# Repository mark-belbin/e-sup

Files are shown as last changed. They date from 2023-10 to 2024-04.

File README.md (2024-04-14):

# eSUP
HW and FW for motorized stand up paddle board (SUP). Includes BMS+Charger, MCU, and Battery-Holder PCBA designs.

## Motivation
1. Cruise around Foster City on a battery powered electric SUP.
2. Learn more about BMS HW and design.
3. Improve STM32 FW skills and knowledge.

## High-Level Block Diagram
Some aspects still TBD, but this is the general idea so far. BMS+Charger PCBA, Battery-Holder PCBAs, and MCU PCBA. May or may not need another custom PCBA for hand controller, might be possible to directly use or modify an OTS hand controller normally used for electric foil boards or skateboards.
System Block Diagram

## Battery Configuration

## Power Architecture

## Mechanical Design

## PCBA Design

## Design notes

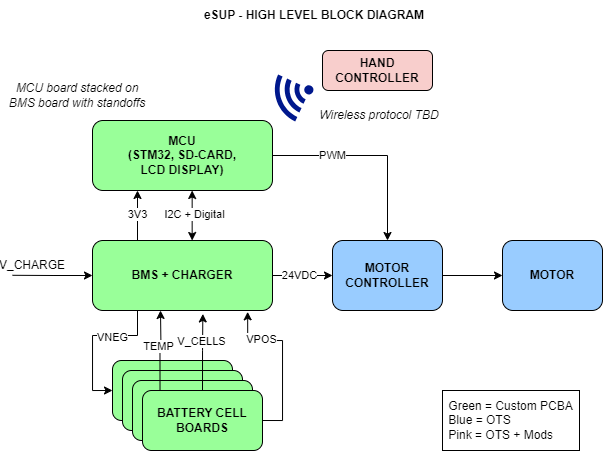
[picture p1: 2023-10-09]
docs/system_block_diagram.png

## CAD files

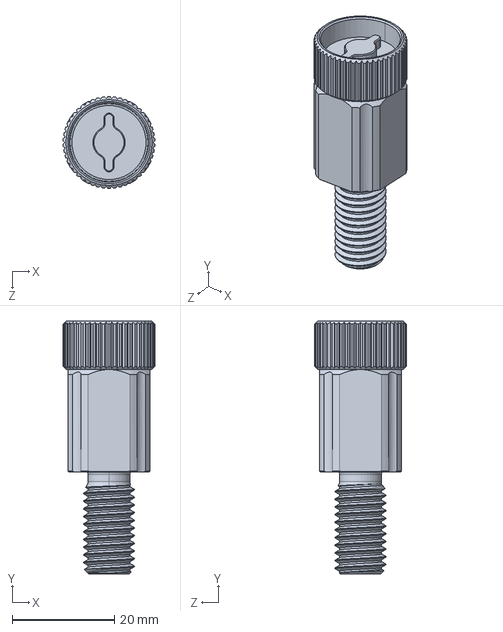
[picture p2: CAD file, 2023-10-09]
mechanical/blue_robotics/PRV-M10-ASM-R1-RP.SLDPRT
18.0 x 49.5 x 18.0 mm

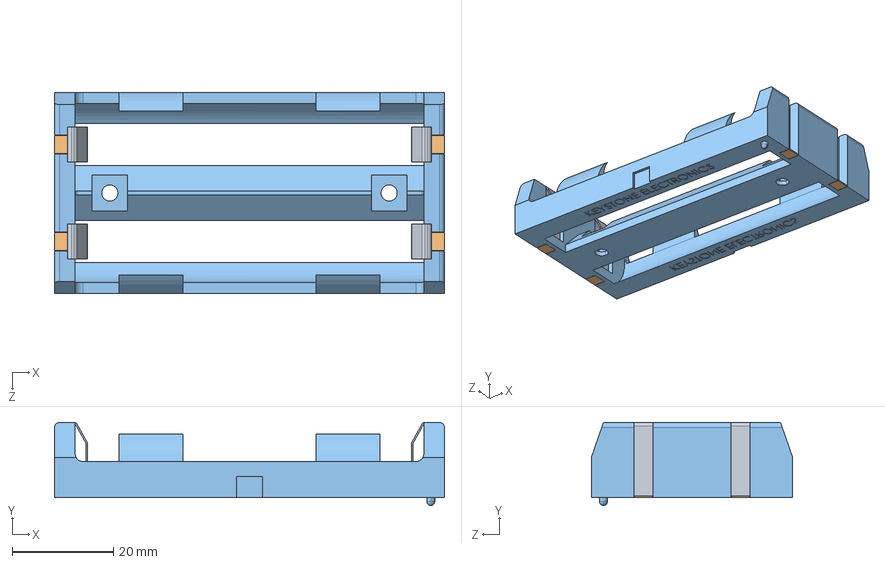
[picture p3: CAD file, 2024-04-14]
hardware/10p-battery-board/3d_models/HOLDER, DUAL, KEYSTONE.STEP
77.1 x 16.4 x 39.8 mm

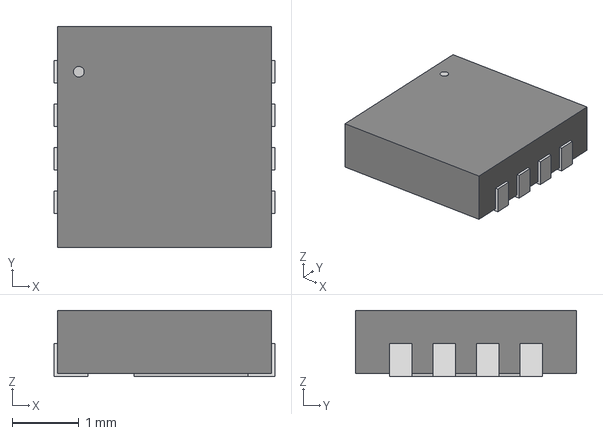
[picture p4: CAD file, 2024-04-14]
hardware/bms/3d_models/PG-TSDSON-8-12_INF.step
3.30 x 3.30 x 0.993 mm

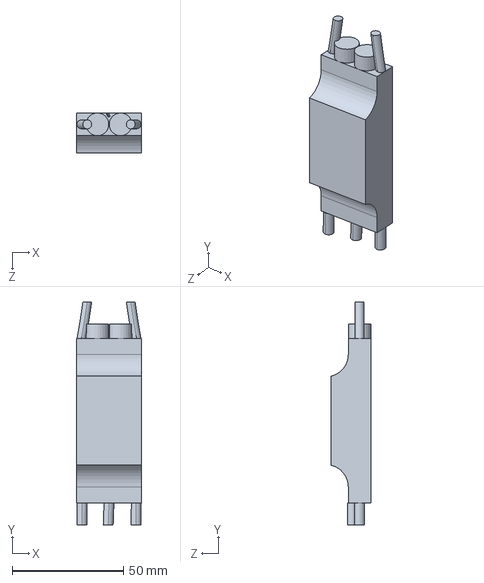
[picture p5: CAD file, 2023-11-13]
mechanical/blue_robotics/BESC500-R1.SLDPRT
29.0 x 100.2 x 18.0 mm

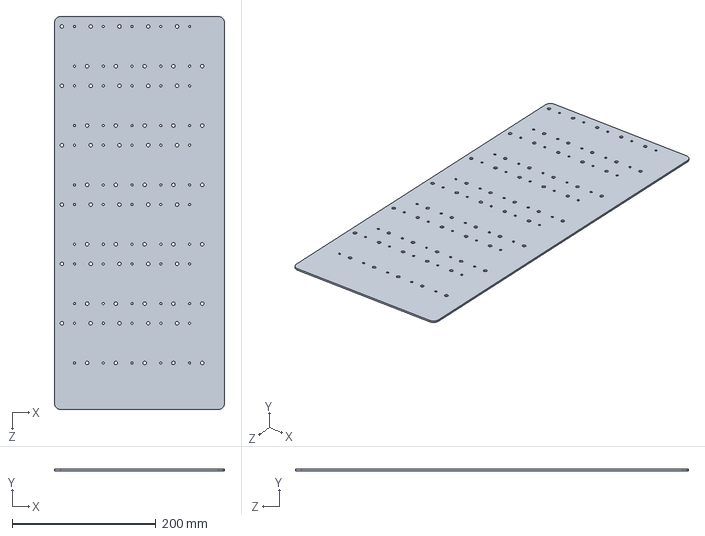
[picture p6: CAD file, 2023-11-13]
mechanical/enclosure/ENCLOSURE, PLATE.SLDPRT
236.3 x 2.29 x 546.3 mm

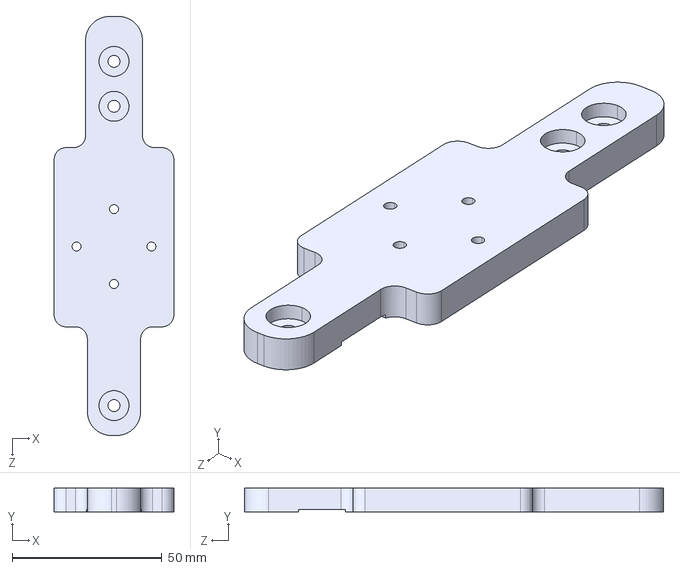
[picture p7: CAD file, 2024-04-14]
mechanical/step_files/SUP, FIN, MOUNT.STEP
40.0 x 8.00 x 140.0 mm

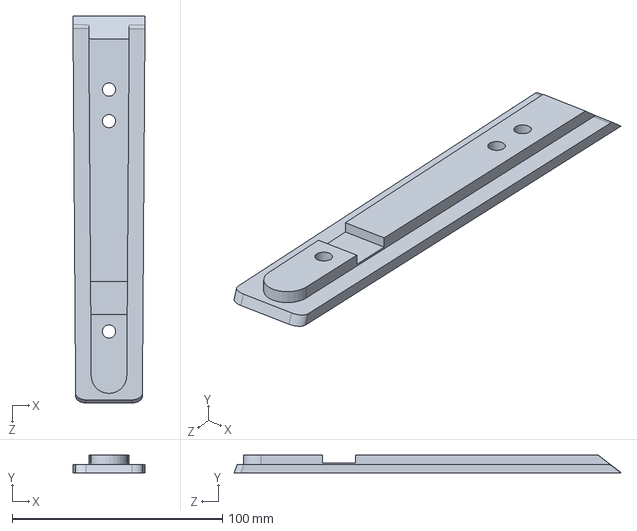
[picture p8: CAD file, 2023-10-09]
mechanical/sup/SUP, FIN, BASE.SLDPRT
34.3 x 8.50 x 184.0 mm

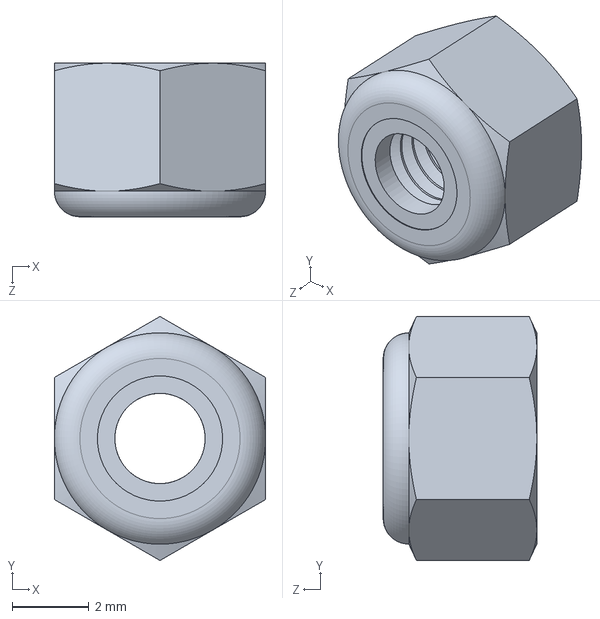
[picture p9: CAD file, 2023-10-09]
mechanical/ots_hardware/LOCKNUT, M3, 90576A102.SLDPRT
5.50 x 6.35 x 4.00 mm

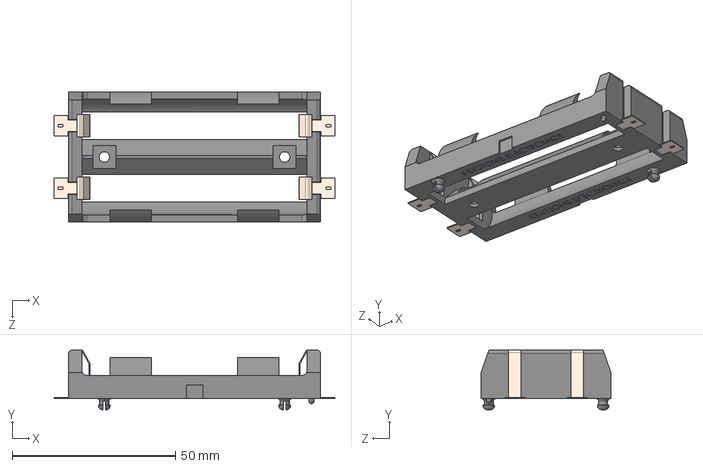
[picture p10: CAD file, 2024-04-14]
mechanical/step_files/Keystone-1048.stp
86.0 x 18.3 x 39.8 mm

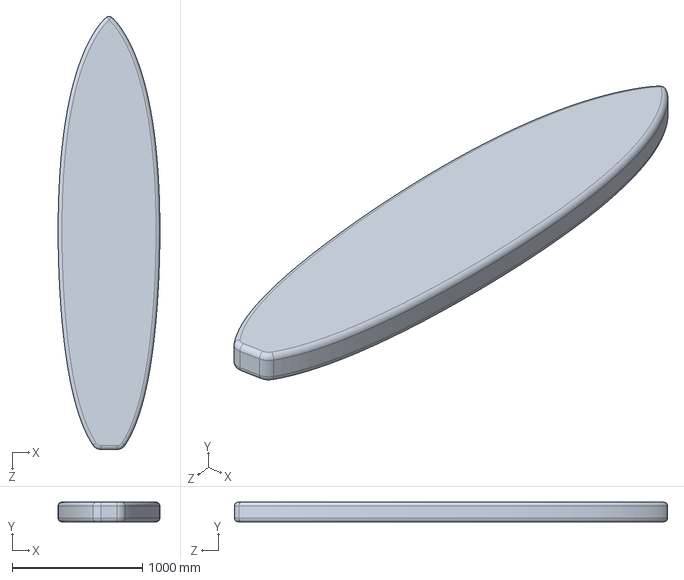
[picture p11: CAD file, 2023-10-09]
mechanical/sup/SUP, BODY.SLDPRT
781.7 x 152.4 x 3322.7 mm

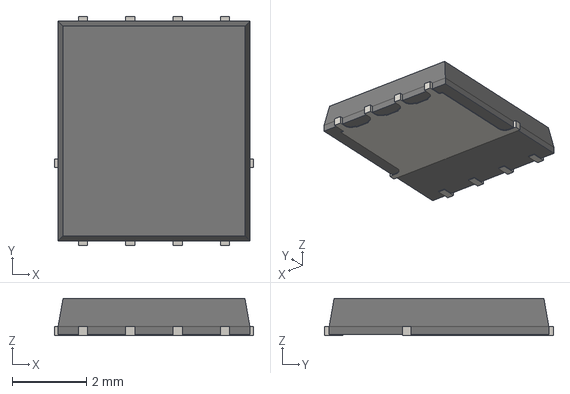
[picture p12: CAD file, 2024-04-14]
hardware/bms/3d_models/TDSON-8-1.step
5.35 x 6.15 x 1.00 mm

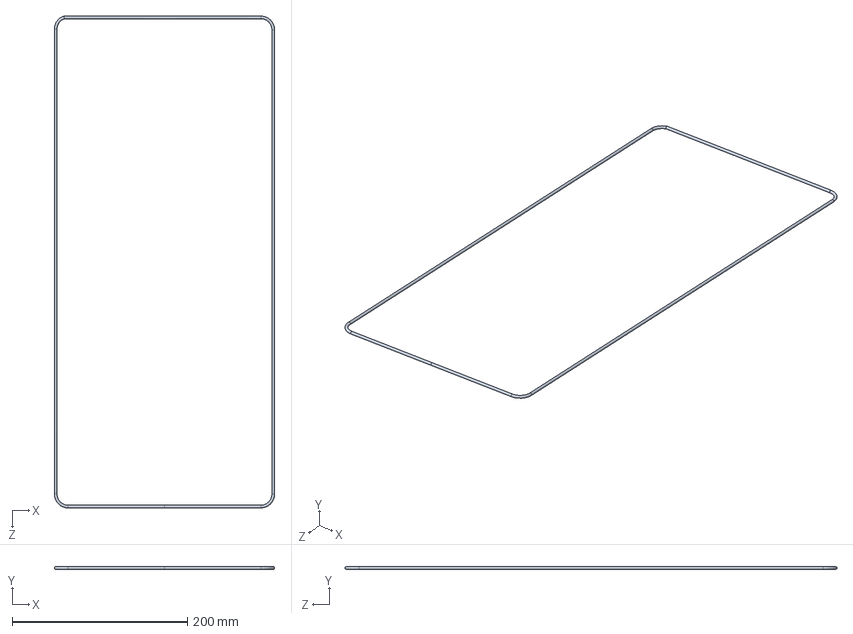
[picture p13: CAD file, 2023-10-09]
mechanical/enclosure/ENCLOSURE, ORING, 1-8IN, 9679K15.SLDPRT
251.4 x 3.17 x 561.4 mm

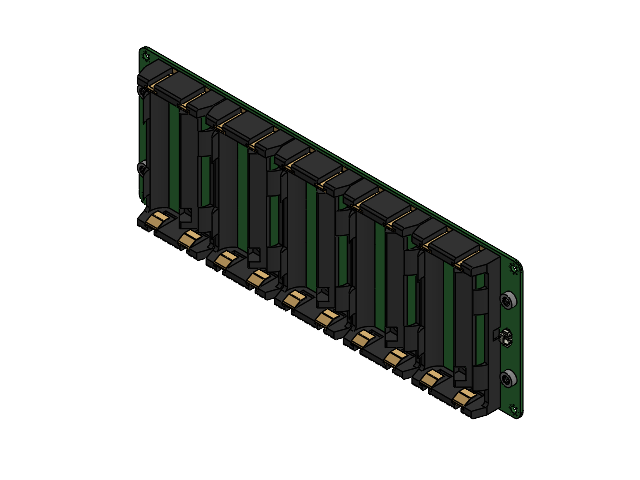
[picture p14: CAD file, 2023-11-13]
mechanical/battery/PCBA, BATTERY BOARD.SLDASM
COMPOUND.step x 5
SOLID.step x 4
SOLID-0.step
10p-battery-holder PCB.step

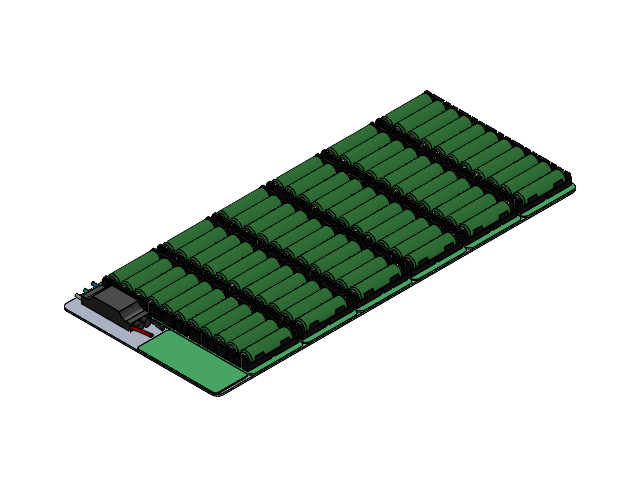
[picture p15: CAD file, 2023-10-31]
mechanical/enclosure/ENCLOSURE, PLATE, ASM.SLDASM
ENCLOSURE, PLATE
PCB, 11X BATTERY HOLDER x 6
HOLDER, DUAL, KEYSTONE x 30
BATTERY, 18650 x 60
NUT, M3, THIN, 90370A203 x 60
BESC500-R1
SCREW, M3, 8MM, FLAT, HEX, 92125A128 x 60
PCB, BMS

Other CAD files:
mechanical/battery/HOLDER, PCBA, ASM.SLDASM
mechanical/battery/HOLDER, DUAL, ASM.SLDASM
mechanical/battery/HOLDER, SINGLE, ASM.SLDASM
mechanical/battery/HOLDER, DUAL, KEYSTONE.SLDPRT
hardware/10p-battery-board/3d_models/746600430.stp
hardware/bms/3d_models/0679L9150-01.step
hardware/bms/3d_models/1040310811.stp
hardware/bms/3d_models/436500214.stp
hardware/bms/3d_models/5019.step
hardware/bms/3d_models/503398-1892.step
hardware/bms/3d_models/532611071.step
hardware/bms/3d_models/746600430.stp
hardware/bms/3d_models/7466114.stp
hardware/bms/3d_models/B3U-1000P.step
hardware/bms/3d_models/CUI_DEVICES_DS04-254-2-01BK-SMT-TR.step
hardware/bms/3d_models/DCK0005A.stp
hardware/bms/3d_models/ETQP5M3R3YFK.step
hardware/bms/3d_models/FUSE_0ACH-9800-TE_BEL.step
hardware/bms/3d_models/HCM1307-R.STEP
hardware/bms/3d_models/IND_1050P-WE-PD_WRE.step
hardware/bms/3d_models/SF-3812F-T.stp
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

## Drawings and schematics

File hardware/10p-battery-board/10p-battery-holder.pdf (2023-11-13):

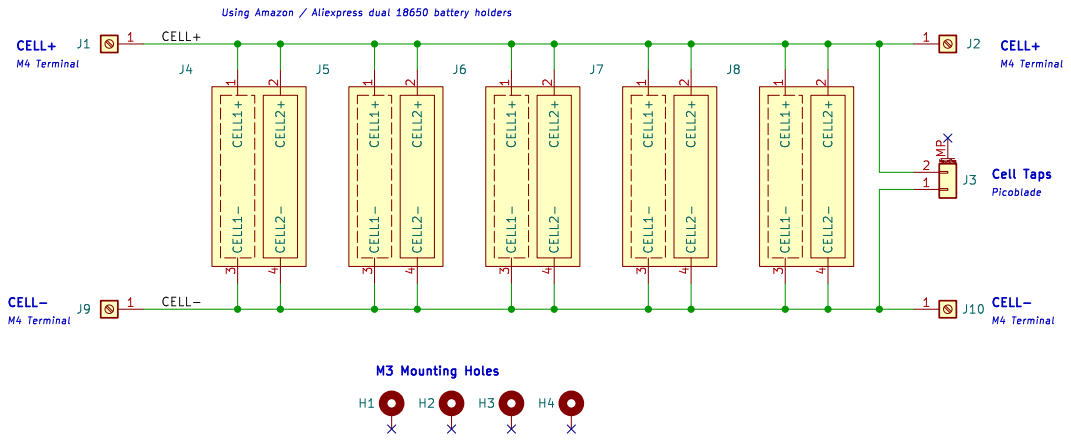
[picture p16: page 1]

M4 Terminal CELL- CELL+ M4 Terminal CELL- M4 Terminal

File: 10p-battery-holder.kicad_sch Sheet: /

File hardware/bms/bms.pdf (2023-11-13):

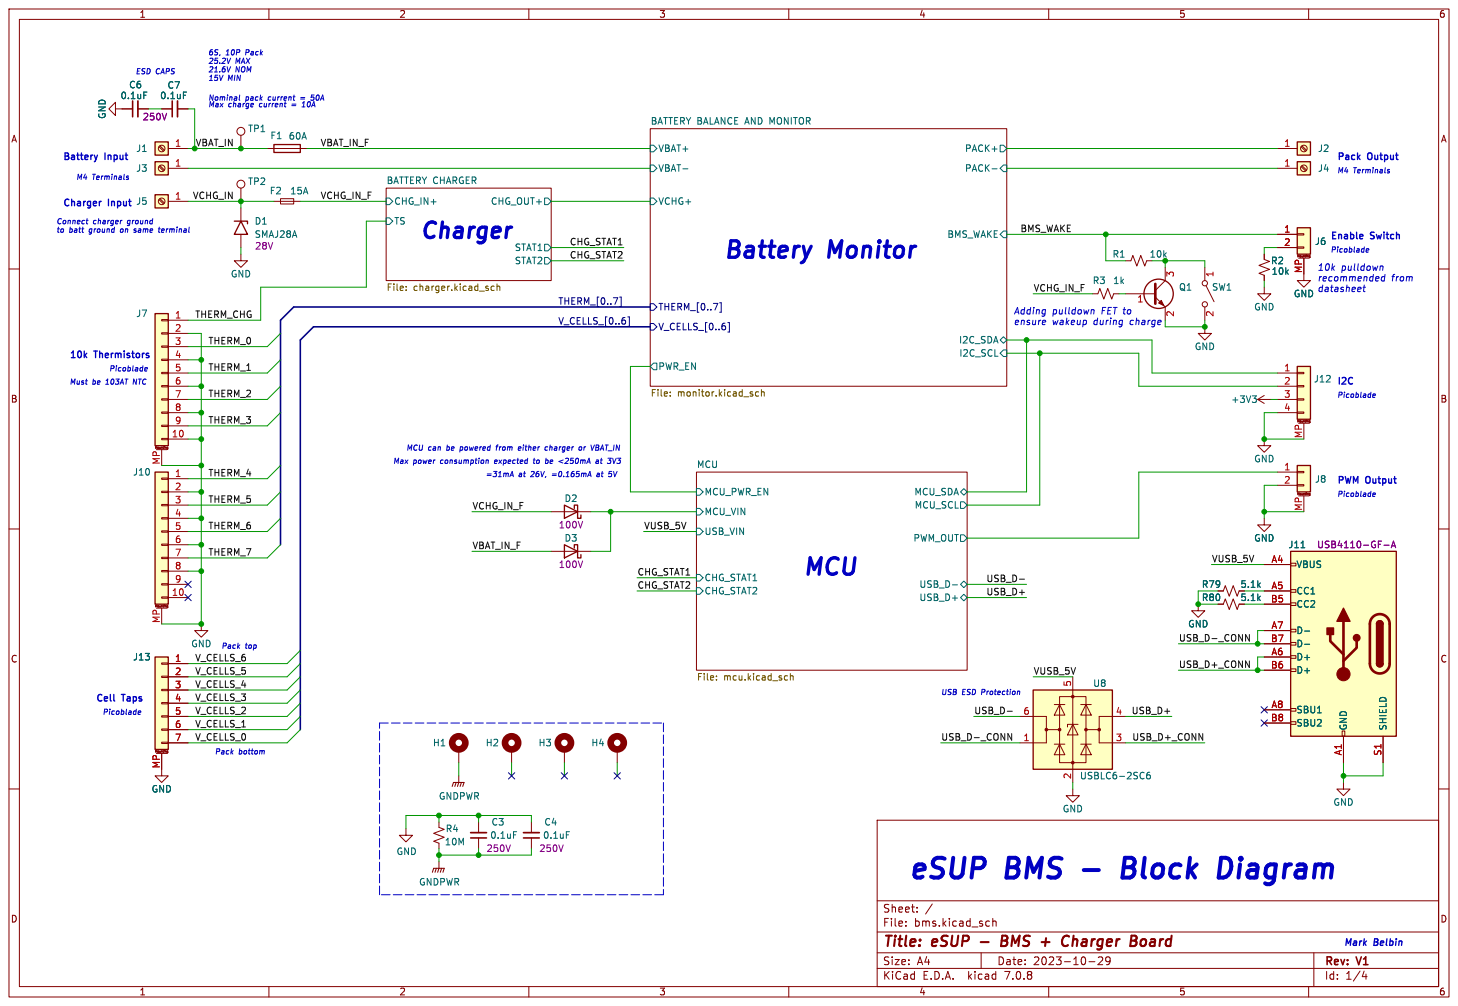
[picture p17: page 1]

PACK+ BATTERY BALANCE AND MONITOR

to batt ground on same terminal Battery Input M4 Terminals Charger Input

Picoblade Must be 103AT NTC Connect charger ground

ensure wakeup during charge

USB ESD Protection Cell Taps
7 MP GND

eSUP BMS - Block Diagram

File: bms.kicad_sch Sheet: /
Id: 1/4 Title: eSUP - BMS + Charger Board

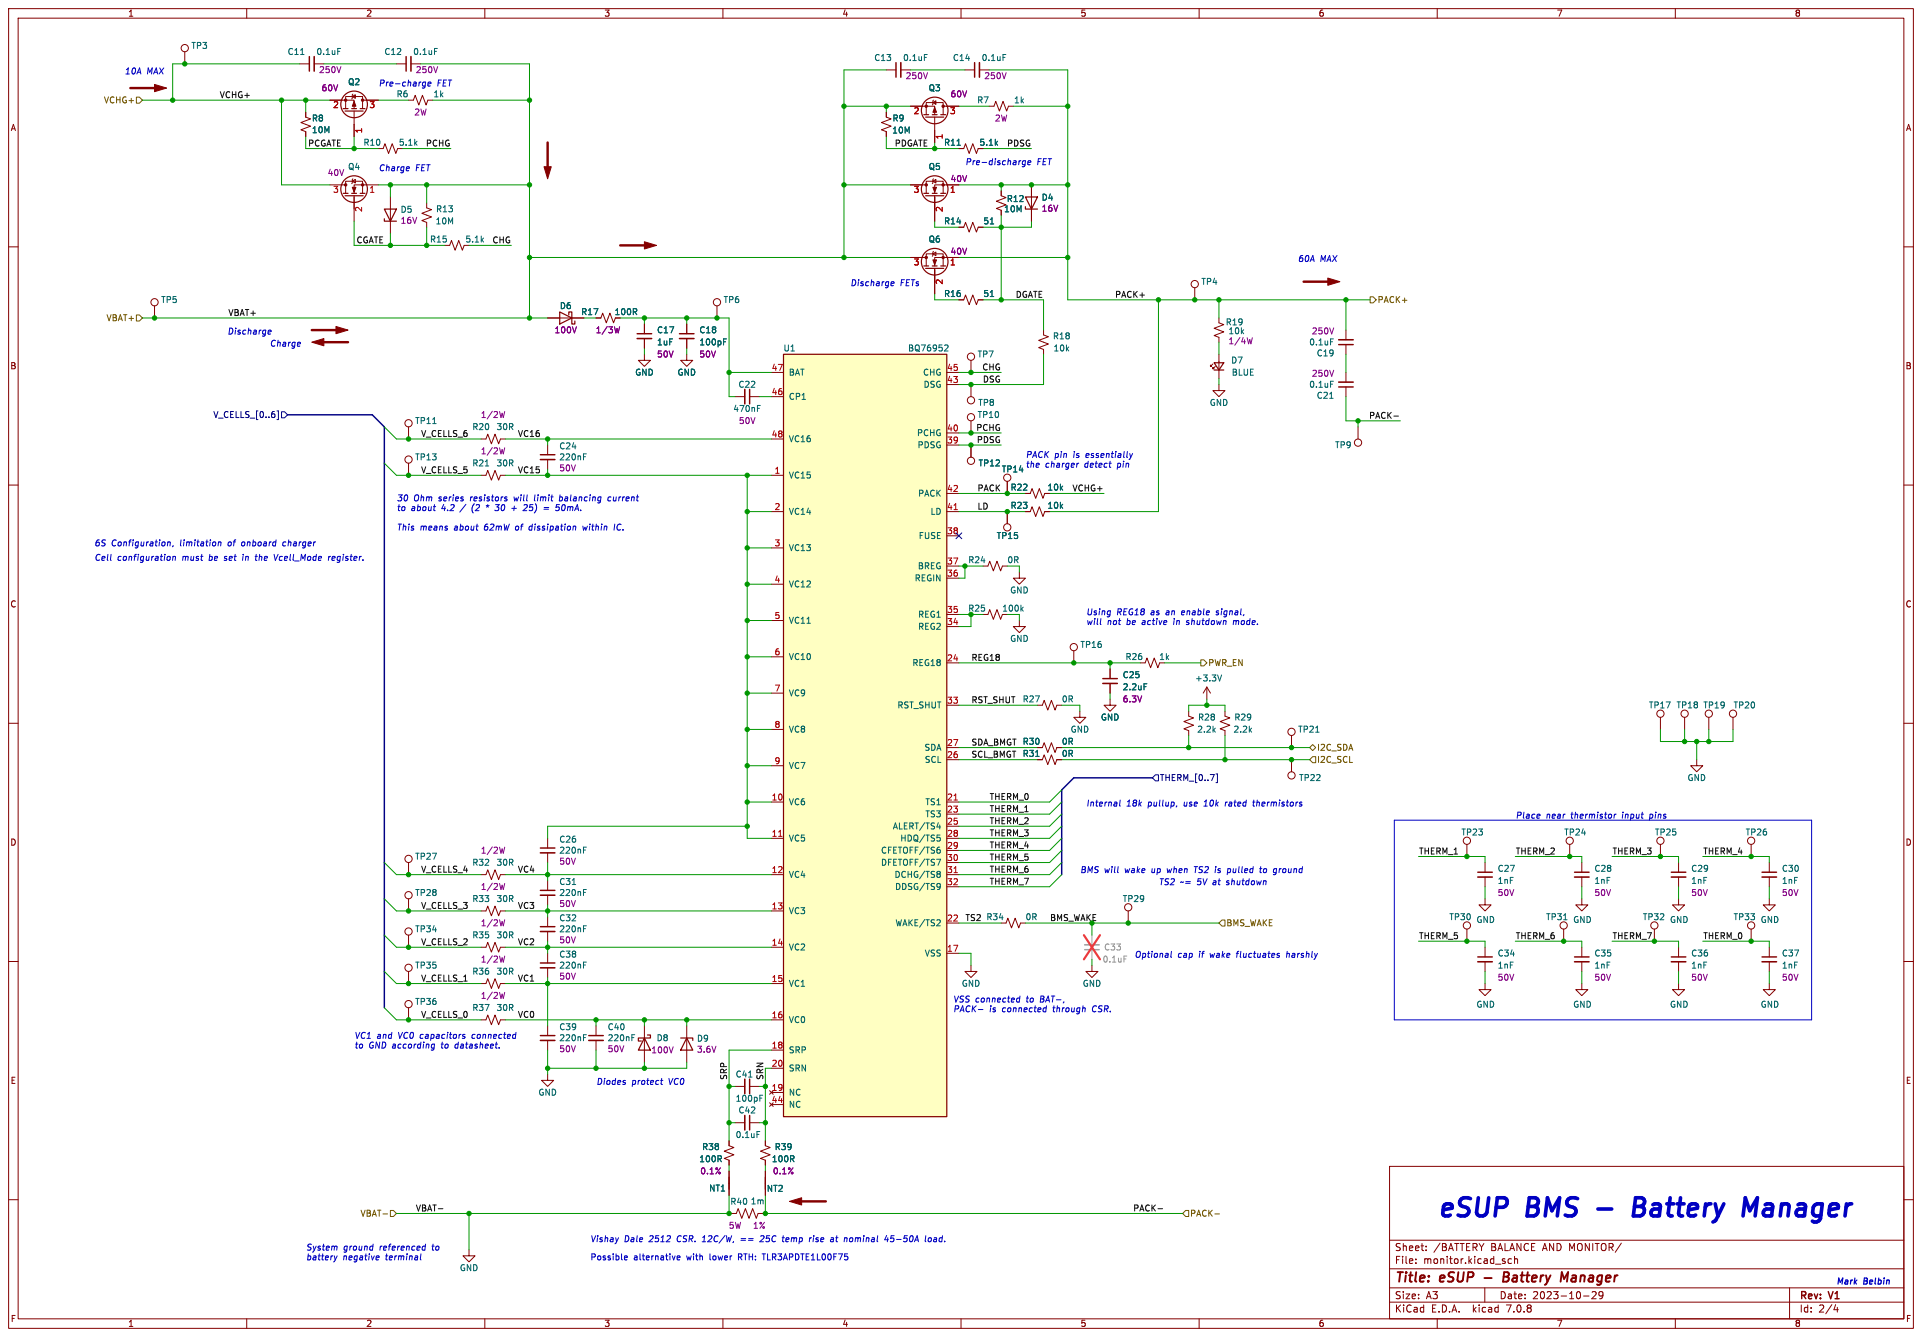
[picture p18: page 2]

the charger detect pin

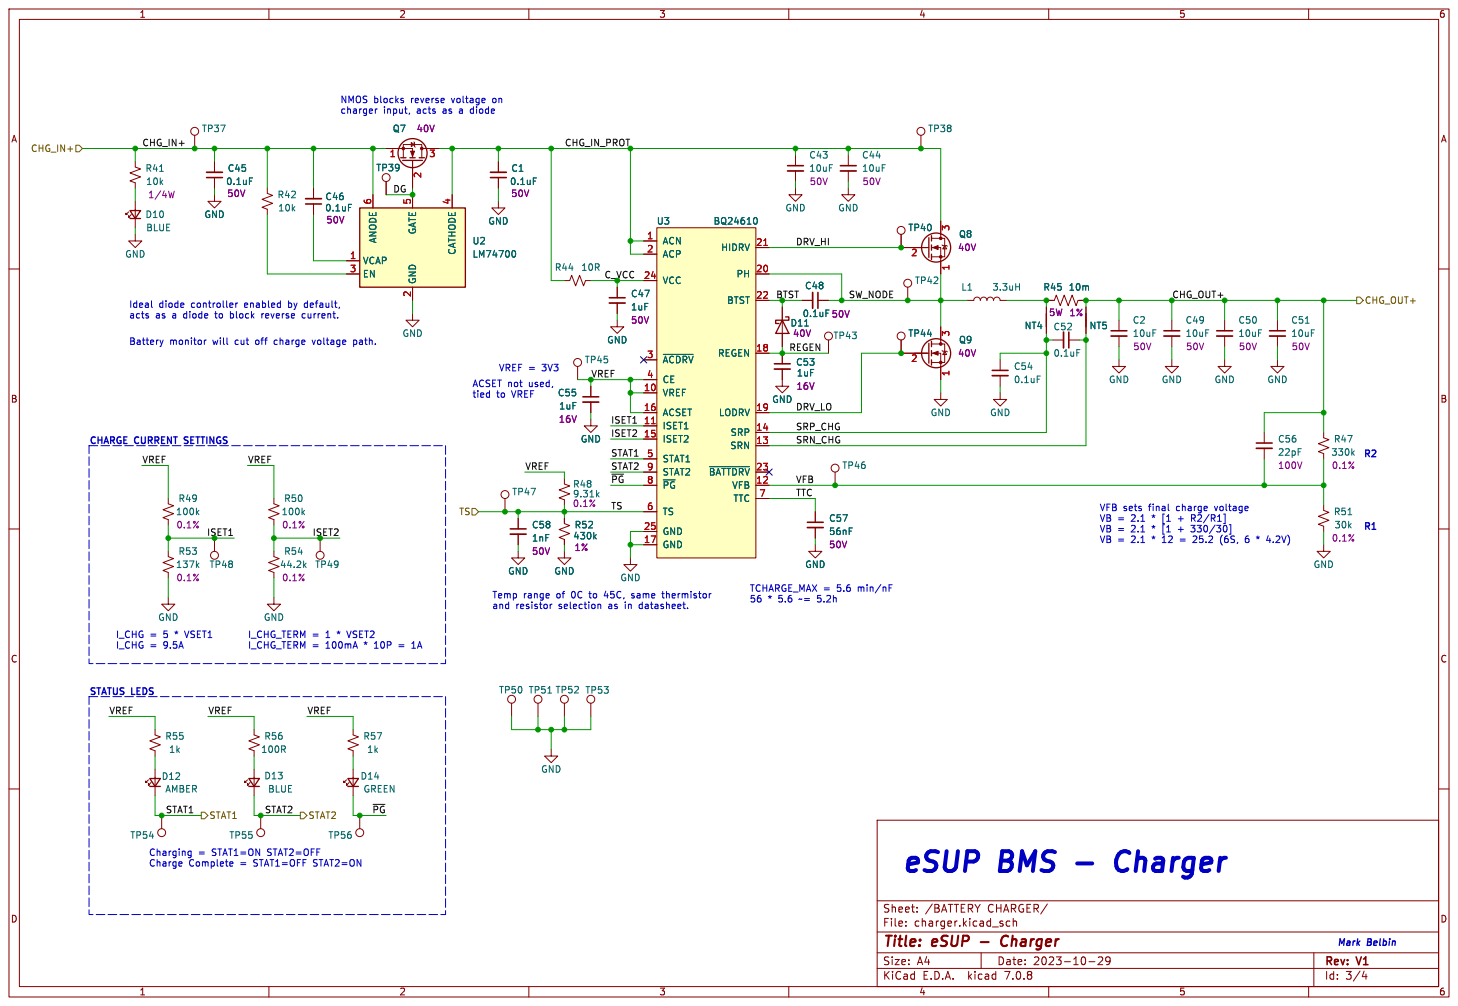
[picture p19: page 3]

NMOS blocks reverse voltage on

VREF = 3V3 ACSET not used,

Id: 3/4 Title: eSUP - Charger File: charger.kicad_sch Sheet: /BATTERY CHARGER/ GND

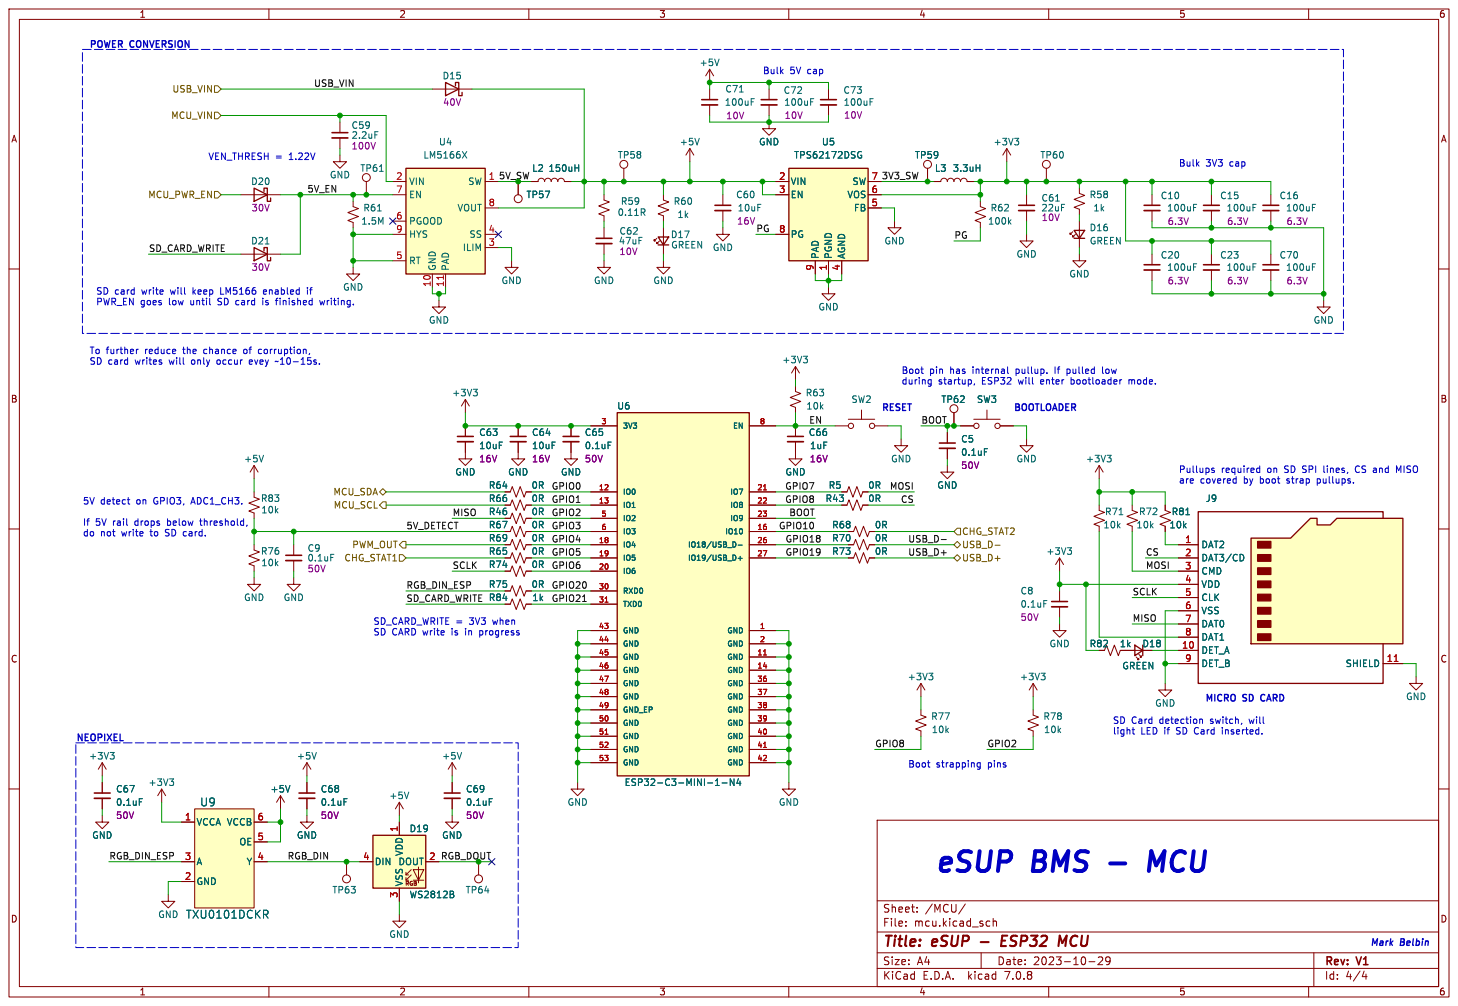
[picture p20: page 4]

are covered by boot strap pullups. VEN_THRESH = 1.22V

4 FB 5 VOS 6 SW 7 PG 8 PAD

light LED if SD Card inserted.

File: mcu.kicad_sch Sheet: /MCU/
Id: 4/4 Title: eSUP - ESP32 MCU

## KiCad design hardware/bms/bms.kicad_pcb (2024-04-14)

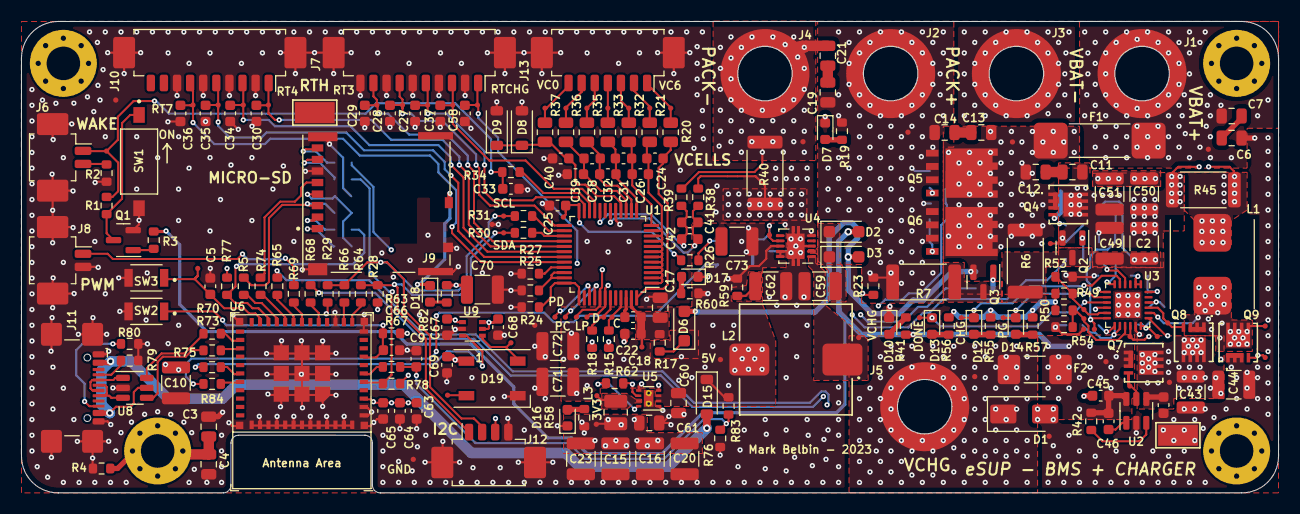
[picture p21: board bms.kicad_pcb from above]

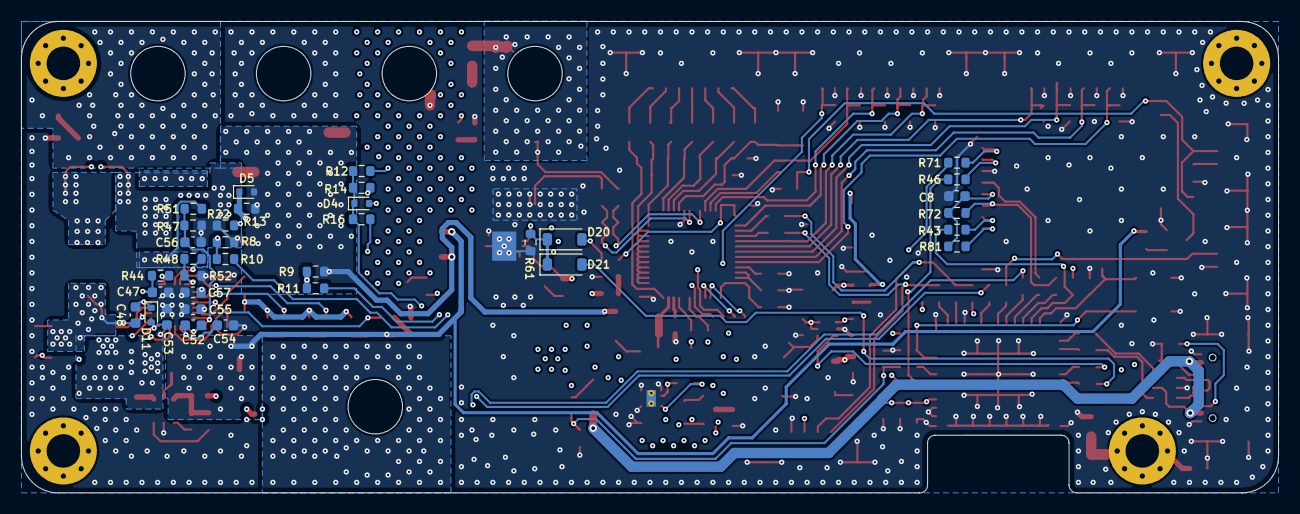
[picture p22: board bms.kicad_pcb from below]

Board: 4 copper layers, 120.0 x 45.0 mm, 287 parts (34 on the bottom side), 144 nets.

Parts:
C1, C5, C8, C9, C33, C42, C45, C46, C48, C52, C54, C65, C67, C68, C69: 0.1uF; C_0603_1608Metric
C2, C43, C44, C49, C50, C51: 10uF; C_1210_3225Metric
C3, C4, C6, C7, C11, C12, C13, C14, C19, C21: 0.1uF; C_0805_2012Metric
C10, C15, C16, C20, C23, C70, C71, C72, C73: 100uF; C_1210_3225Metric
C17: 1uF; C_0805_2012Metric
C18, C41: 100pF; C_0603_1608Metric
C22: 470nF; C_0603_1608Metric
C24, C26, C31, C32, C38, C39, C40: 220nF; C_0603_1608Metric
C25: 2.2uF; C_0603_1608Metric
C27, C28, C29, C30, C34, C35, C36, C37, C58: 1nF; C_0603_1608Metric
C47, C53, C55, C66: 1uF; C_0603_1608Metric
C56: 22pF; C_0603_1608Metric
C57: 56nF; C_0603_1608Metric
C59: 2.2uF; C_1210_3225Metric
C60: 10uF; C_0805_2012Metric
C61: 22uF; C_0805_2012Metric
C62: 47uF; C_1210_3225Metric
C63, C64: 10uF; C_0603_1608Metric
D1: SMAJ28A; D_SMA
D2, D3, D6: D_Schottky; D_SOD-123F
D4, D5: D_Zener; D_SOD-523
D7, D10, D13: BLUE; LED_0603_1608Metric
D8, D15, D20, D21: D_Schottky; D_SOD-123
D9: D_Zener; D_SOD-123
D11: D_Schottky; D_SOD-523
D12: AMBER; LED_0603_1608Metric
D14, D16, D17, D18: GREEN; LED_0603_1608Metric
D19: WS2812B; LED_WS2812B_PLCC4_5.0x5.0mm_P3.2mm
F1: 60A; SF-3812F6000T-2
F2: 15A; FUSC6125X279N
H1, H2, H3, H4: MountingHole_Pad; MountingHole_3.2mm_M3_Pad_Via
J1, J2, J3, J4, J5: Screw_Terminal_01x01; Wurth_746600430R
J6, J8: Conn_01x02; Molex_PicoBlade_53261-0271_1x02-1MP_P1.25mm_Horizontal
J7, J10: Conn_01x10; Molex_PicoBlade_53261-1071_1x10-1MP_P1.25mm_Horizontal
J9: Micro_SD_Card_Det2; MOLEX_503398-1892
J11: USB_C_Receptacle_USB2.0; USB_C_Receptacle_GCT_USB4110
J12: Conn_01x03; Molex_PicoBlade_53261-0471_1x04-1MP_P1.25mm_Horizontal
J13: Conn_01x07; Molex_PicoBlade_53261-0771_1x07-1MP_P1.25mm_Horizontal
L1: 3.3uH; IND_ETQP5M3R3YFK
L2: 150uH; IND_1050P-WE-PD_WRE-L
L3: 3.3uH; L_1008_2520Metric
NT1, NT2, NT4, NT5: Net-Tie; NetTie-2_SMD_Pad_8mil
Q1: MMBT3904; SOT-23
Q2, Q3: Q_PMOS_GSD; SOT-23
Q4, Q7, Q8, Q9: BSZ018N04LS6ATMA1; PG-TSDSON-8-26_INF
Q5, Q6: IAUC120N04S6N006ATMA1; PG-TDSON-8
R1, R2, R18, R19, R22, R23, R41, R42, R63, R71, R72, R76, R77, R78, R81, R83: 10k; R_0603_1608Metric
R3, R26, R55, R57, R58, R60, R82, R84: 1k; R_0603_1608Metric
R4, R8, R9, R12, R13: 10M; R_0603_1608Metric
R5, R24, R27, R30, R31, R34, R43, R46, R64, R65, R66, R67, R68, R69, R70, R73, R74, R75: 0R; R_0603_1608Metric
R6, R7: 1k; R_2512_6332Metric
R10, R11, R15, R79, R80: 5.1k; R_0603_1608Metric
R14, R16: 51; R_0603_1608Metric
R17, R38, R39, R56: 100R; R_0603_1608Metric
R20, R21, R32, R33, R35, R36, R37: 30R; R_0805_2012Metric
R25, R49, R50, R62: 100k; R_0603_1608Metric
R28, R29: 2.2k; R_0603_1608Metric
R40: 1m; R_2512_6332Metric
R44: 10R; R_0603_1608Metric
R45: 10m; R_2512_6332Metric
R47: 330k; R_0603_1608Metric
R48: 9.31k; R_0603_1608Metric
R51: 30k; R_0603_1608Metric
R52: 430k; R_0603_1608Metric
R53: 137k; R_0603_1608Metric
R54: 44.2k; R_0603_1608Metric
R59: 0.11R; R_0603_1608Metric
R61: 1.5M; R_0603_1608Metric
SW1: SW_SPST; SW_DS04-254-2-01BK-SMT-TR
SW2, SW3: SW_Push; SW_B3U-1000P
TP1, TP2, TP3, TP4, TP5, TP6, TP7, TP8, TP9, TP10, TP11, TP12, TP13, TP14, TP15, TP16, TP19, TP20, TP21, TP22, TP23, TP24, TP25, TP26, TP27, TP28, TP29, TP30, TP31, TP32, TP33, TP34, TP35, TP36, TP37, TP38, TP39, TP40, TP42, TP43, TP44, TP45, TP46, TP47, TP48, TP49, TP50, TP51, TP52, TP53, TP54, TP55, TP56, TP57, TP58, TP59, TP60, TP61, TP62, TP63, TP64: TestPoint; TestPoint_Pad_D0.5mm
TP17, TP18: TestPoint; TestPoint_Keystone_5019_Minature
U1: BQ76952; TQFP-48_7x7mm_P0.5mm
U2: LM74700; SOT-23-6
U3: BQ24610; VQFN-24-1EP_4x4mm_P0.5mm_EP2.45x2.45mm
U4: LM5166X; Texas_S-PVSON-N10_ThermalVias
U5: TPS62172DSG; WSON-8-1EP_2x2mm_P0.5mm_EP0.9x1.6mm_ThermalVias
U6: ESP32-C3-MINI-1-N4; ESP32-C3-MINI-1
U8: USBLC6-2SC6; SOT-23-6
U9: TXU0101DCKR; SOT-363_SC-70-6

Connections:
+3V3: C8.1, C10.1, C15.1, C16.1, C20.1, C23.1, C61.1, C63.1, C64.1, C65.1, C67.1, C70.1, J9.4 (VDD), J12.3, L3.2, R28.1, R29.1, R58.2, R62.2, R63.1, R71.1, R72.1, R77.1, R78.1, R81.1, R82.2, TP60.1, U5.6 (VOS), U6.3 (3V3), U9.1 (VCCA)
+5V: C60.1, C68.1, C69.1, C71.1, C72.1, C73.1, D15.1 (K), D19.1 (VDD), L2.2, R59.2, R60.2, R83.1, TP58.1, U4.8 (VOUT), U5.2 (VIN), U5.3 (EN), U9.5 (OE), U9.6 (VCCB)
/BATTERY BALANCE AND MONITOR/CGATE: D5.1 (K), Q4.2 (G), R13.2, R15.1
/BATTERY BALANCE AND MONITOR/CHG: R15.2, TP7.1, U1.45 (CHG)
/BATTERY BALANCE AND MONITOR/DGATE: D4.1 (K), R12.2, R14.2, R16.2, R18.1
/BATTERY BALANCE AND MONITOR/DSG: R18.2, TP8.1, U1.43 (DSG)
/BATTERY BALANCE AND MONITOR/I2C_SCL: J12.2, R29.2, R31.2, R66.1, TP22.1
/BATTERY BALANCE AND MONITOR/I2C_SDA: J12.1, R28.2, R30.2, R64.1, TP21.1
/BATTERY BALANCE AND MONITOR/LD: R23.1, TP15.1, U1.41 (LD)
/BATTERY BALANCE AND MONITOR/PACK: R22.1, TP14.1, U1.42 (PACK)
/BATTERY BALANCE AND MONITOR/PACK+: C14.2, C19.2, D4.2 (A), J2.1, Q5.1 (S), Q6.1 (S), R7.2, R12.1, R19.1, R23.2, TP4.1
/BATTERY BALANCE AND MONITOR/PACK-: C21.1, J4.1, NT2.2, R40.1, TP9.1
/BATTERY BALANCE AND MONITOR/PCGATE: Q2.1 (G), R8.2, R10.1
/BATTERY BALANCE AND MONITOR/PCHG: R10.2, TP10.1, U1.40 (PCHG)
/BATTERY BALANCE AND MONITOR/PDGATE: Q3.1 (G), R9.2, R11.1
/BATTERY BALANCE AND MONITOR/PDSG: R11.2, TP12.1, U1.39 (PDSG)
/BATTERY BALANCE AND MONITOR/PWR_EN: D20.2 (A), R26.1
/BATTERY BALANCE AND MONITOR/REG18: C25.1, R26.2, TP16.1, U1.24 (REG18)
/BATTERY BALANCE AND MONITOR/RST_SHUT: R27.1, U1.33 (RST_SHUT)
/BATTERY BALANCE AND MONITOR/SCL_BMGT: R31.1, U1.26 (SCL)
/BATTERY BALANCE AND MONITOR/SDA_BMGT: R30.1, U1.27 (SDA)
/BATTERY BALANCE AND MONITOR/SRN: C41.1, C42.1, R39.1, U1.20 (SRN)
/BATTERY BALANCE AND MONITOR/SRP: C41.2, C42.2, R38.1, U1.18 (SRP)
/BATTERY BALANCE AND MONITOR/TS2: R34.1, U1.22 (WAKE/TS2)
/BATTERY BALANCE AND MONITOR/VC0: C40.1, D8.1 (K), D9.1 (K), R37.1, U1.16 (VC0)
/BATTERY BALANCE AND MONITOR/VC1: C38.2, C39.1, R36.1, U1.15 (VC1)
/BATTERY BALANCE AND MONITOR/VC2: C32.2, C38.1, R35.1, U1.14 (VC2)
/BATTERY BALANCE AND MONITOR/VC3: C31.2, C32.1, R33.1, U1.13 (VC3)
/BATTERY BALANCE AND MONITOR/VC4: C26.2, C31.1, R32.1, U1.12 (VC4)
/BATTERY BALANCE AND MONITOR/VC15: C24.2, C26.1, R21.1, U1.1 (VC15), U1.2 (VC14), U1.3 (VC13), U1.4 (VC12), U1.5 (VC11), U1.6 (VC10), U1.7 (VC9), U1.8 (VC8), U1.9 (VC7), U1.10 (VC6), U1.11 (VC5)
/BATTERY BALANCE AND MONITOR/VC16: C24.1, R20.1, U1.48 (VC16)
/BATTERY BALANCE AND MONITOR/VCHG+: C2.1, C11.1, C49.1, C50.1, C51.1, C56.1, NT5.1, Q2.2 (S), Q4.3 (D), R8.1, R22.2, R45.1, R47.2, TP3.1
/BATTERY CHARGER/BTST: C48.2, D11.1 (K), U3.22 (BTST)
/BATTERY CHARGER/CHG_IN_PROT: C1.2, C43.1, C44.1, Q7.3 (D), Q8.3 (D), R44.1, TP38.1, U2.4 (CATHODE), U3.1 (ACN), U3.2 (ACP)
/BATTERY CHARGER/C_VCC: C47.1, R44.2, U3.24 (VCC)
/BATTERY CHARGER/DG: Q7.2 (G), TP39.1, U2.5 (GATE)
/BATTERY CHARGER/DRV_HI: Q8.2 (G), TP40.1, U3.21 (HIDRV)
/BATTERY CHARGER/DRV_LO: Q9.2 (G), TP44.1, U3.19 (LODRV)
/BATTERY CHARGER/ISET1: R49.1, R53.2, TP48.1, U3.11 (ISET1)
/BATTERY CHARGER/ISET2: R50.1, R54.2, TP49.1, U3.15 (ISET2)
/BATTERY CHARGER/REGEN: C53.1, D11.2 (A), TP43.1, U3.18 (REGEN)
/BATTERY CHARGER/SRN_CHG: C52.1, NT5.2, U3.13 (SRN)
/BATTERY CHARGER/SRP_CHG: C52.2, C54.1, NT4.2, U3.14 (SRP)
/BATTERY CHARGER/SW_NODE: C48.1, L1.1, Q8.1 (S), Q9.3 (D), TP42.1, U3.20 (PH)
/BATTERY CHARGER/TTC: C57.1, U3.7 (TTC)
/BATTERY CHARGER/VFB: C56.2, R47.1, R51.2, TP46.1, U3.12 (VFB)
/BATTERY CHARGER/VREF: C55.1, R48.2, R49.2, R50.2, R55.2, R56.2, R57.2, TP45.1, U3.4 (CE), U3.10 (VREF), U3.16 (ACSET)
/BATTERY CHARGER/~PG: D14.1 (K), TP56.1, U3.8 (~PG)
/BMS_WAKE: C33.2, J6.1, R1.1, R34.2, TP29.1
/CHG_STAT1: D12.1 (K), R65.1, TP54.1, U3.5 (STAT1)
/CHG_STAT2: D13.1 (K), R68.2, TP55.1, U3.9 (STAT2)
/MCU/3V3_SW: L3.1, TP59.1, U5.7 (SW)
/MCU/5V_DETECT: C9.1, R67.1, R76.1, R83.2
/MCU/5V_EN: D20.1 (K), D21.1 (K), R61.2, TP61.1, U4.7 (EN)
/MCU/5V_SW: L2.1, TP57.1, U4.1 (SW)
/MCU/BOOT: C5.1, SW3.1, TP62.1, U6.23 (IO9)
/MCU/CS: J9.2 (DAT3/CD), R43.2
/MCU/EN: C66.1, R63.2, SW2.1, U6.8 (EN)
/MCU/GPIO0: R64.2, U6.12 (IO0)
/MCU/GPIO1: R66.2, U6.13 (IO1)
/MCU/GPIO2: R46.2, R78.2, U6.5 (IO2)
/MCU/GPIO3: R67.2, U6.6 (IO3)
/MCU/GPIO4: R69.2, U6.18 (IO4)
/MCU/GPIO5: R65.2, U6.19 (IO5)
/MCU/GPIO6: R74.2, U6.20 (IO6)
/MCU/GPIO7: R5.1, U6.21 (IO7)
/MCU/GPIO8: R43.1, R77.2, U6.22 (IO8)
/MCU/GPIO10: R68.1, U6.16 (IO10)
/MCU/GPIO18: R70.1, U6.26 (IO18/USB_D-)
/MCU/GPIO19: R73.1, U6.27 (IO19/USB_D+)
/MCU/GPIO20: R75.2, U6.30 (RXD0)
/MCU/GPIO21: R84.1, U6.31 (TXD0)
/MCU/MCU_VIN: C59.1, D2.1 (K), D3.1 (K), U4.2 (VIN)
/MCU/MISO: J9.7 (DAT0), R46.1
/MCU/MOSI: J9.3 (CMD), R5.2, R72.2
/MCU/PG: R62.1, U5.8 (PG)
/MCU/PWM_OUT: J8.1, R69.1
/MCU/RGB_DIN: D19.4 (DIN), TP63.1, U9.4 (Y)
/MCU/RGB_DIN_ESP: R75.1, U9.3 (A)
/MCU/RGB_DOUT: D19.2 (DOUT), TP64.1
/MCU/SCLK: J9.5 (CLK), R74.1
/MCU/SD_CARD_WRITE: D21.2 (A), R84.2
/THERM_0: C37.1, J7.3, TP33.1, U1.21 (TS1)
/THERM_1: C27.1, J7.5, TP23.1, U1.23 (TS3)
/THERM_2: C28.1, J7.7, TP24.1, U1.25 (ALERT/TS4)
/THERM_3: C29.1, J7.9, TP25.1, U1.28 (HDQ/TS5)
/THERM_4: C30.1, J10.1, TP26.1, U1.29 (CFETOFF/TS6)
/THERM_5: C34.1, J10.3, TP30.1, U1.30 (DFETOFF/TS7)
/THERM_6: C35.1, J10.5, TP31.1, U1.31 (DCHG/TS8)
/THERM_7: C36.1, J10.7, TP32.1, U1.32 (DDSG/TS9)
/THERM_CHG: C58.1, J7.1, R48.1, R52.2, TP47.1, U3.6 (TS)
/USB_D+: R73.2, U8.4 (I/O2)
/USB_D+_CONN: J11.A6 (D+), J11.B6 (D+), U8.3 (I/O2)
/USB_D-: R70.2, U8.6 (I/O1)
/USB_D-_CONN: J11.A7 (D-), J11.B7 (D-), U8.1 (I/O1)
/VBAT_IN: C7.2, F1.1, J1.1, TP1.1
/VBAT_IN_F: C12.2, C13.1, D3.2 (A), D5.2 (A), D6.2 (A), F1.2, Q3.2 (S), Q4.1 (S), Q5.3 (D), Q6.3 (D), R6.2, R9.1, R13.1, TP5.1
/VCHG_IN: D1.1 (A1), F2.1, J5.1, TP2.1
/VCHG_IN_F: C45.2, C46.2, D2.2 (A), F2.2, Q7.1 (S), R3.2, R41.1, R42.1, TP37.1, U2.6 (ANODE)
/VUSB_5V: D15.2 (A), J11.A4 (VBUS), J11.A9 (VBUS), J11.B4 (VBUS), J11.B9 (VBUS), U8.5 (VBUS)
/V_CELLS_0: J13.7, R37.2, TP36.1
/V_CELLS_1: J13.6, R36.2, TP35.1
/V_CELLS_2: J13.5, R35.2, TP34.1
/V_CELLS_3: J13.4, R33.2, TP28.1
/V_CELLS_4: J13.3, R32.2, TP27.1
/V_CELLS_5: J13.2, R21.2, TP13.1
/V_CELLS_6: J13.1, R20.2, TP11.1
GND: C1.1, C2.2, C3.2, C4.2, C5.2, C6.1, C8.2, C9.2, C10.2, C15.2, C16.2, C17.2, C18.2, C20.2, C23.2, C25.2, C27.2, C28.2, C29.2, C30.2, C33.1, C34.2, C35.2, C36.2, C37.2, C39.2, C40.2, C43.2, C44.2, C45.1, C47.2, C49.2, C50.2, C51.2, C53.2, C54.2, C55.2, C57.2, C58.2, C59.2, C60.2, C61.2, C62.2, C63.2, C64.2, C65.2, C66.2, C67.2, C68.2, C69.2, C70.2, C71.2, C72.2, C73.2, D1.2 (A2), D7.1 (K), D8.2 (A), D9.2 (A), D10.1 (K), D16.1 (K), D17.1 (K), D19.3 (VSS), J3.1, J6.MP (MountPin), J7.2, J7.4, J7.6, J7.8, J7.10, J7.MP (MountPin), J8.2, J8.MP (MountPin), J9.6 (VSS), J9.9 (DET_B), J9.11 (SHIELD), J10.2, J10.4, J10.6, J10.8, J10.MP (MountPin), J11.A1 (GND), J11.A12 (GND), J11.B1 (GND), J11.B12 (GND), J11.S1 (SHIELD), J12.4, J12.MP (MountPin), J13.MP (MountPin), NT1.2, Q1.2 (E), Q9.1 (S), R2.2, R4.1, R24.2, R25.2, R27.2, R40.2, R51.1, R52.1, R53.1, R54.1, R61.1, R76.2, R79.1, R80.1, SW1.2 (B), SW2.2, SW3.2, TP17.1, TP18.1, TP19.1, TP20.1, TP50.1, TP51.1, TP52.1, TP53.1, U1.17 (VSS), U2.2 (GND), U3.17 (GND), U3.25 (GND), U4.3 (ILIM), U4.5 (RT), U4.9 (HYS), U4.10 (GND), U4.11 (PAD), U5.1 (PGND), U5.4 (AGND), U5.5 (FB), U5.9 (PAD), U6.1 (GND), U6.2 (GND), U6.11 (GND), U6.14 (GND), U6.36 (GND), U6.37 (GND), U6.38 (GND), U6.39 (GND), U6.40 (GND), U6.41 (GND), U6.42 (GND), U6.43 (GND), U6.44 (GND), U6.45 (GND), U6.46 (GND), U6.47 (GND), U6.48 (GND), U6.49 (GND_EP), U6.50 (GND), U6.51 (GND), U6.52 (GND), U6.53 (GND), U8.2 (GND), U9.2 (GND)
GNDPWR: C3.1, C4.1, H1.1, R4.2
unnamed: C6.2, C7.1
unnamed: C11.2, C12.1
unnamed: C13.2, C14.1
unnamed: C19.1, C21.2
unnamed: C62.1, R59.1
unnamed: D6.1 (K), R17.1
unnamed: D7.2 (A), R19.2
unnamed: D10.2 (A), R41.2
unnamed: D12.2 (A), R55.1
unnamed: D13.2 (A), R56.1
unnamed: D14.2 (A), R57.1
unnamed: D16.2 (A), R58.1
unnamed: D17.2 (A), R60.1
unnamed: D18.2 (A), R82.1
unnamed: D18.1 (K), J9.10 (DET_A)
unnamed: J6.2, R2.1
unnamed: J9.8 (DAT1), R71.2
unnamed: J9.1 (DAT2), R81.2
unnamed: J11.A5 (CC1), R79.2
unnamed: J11.B5 (CC2), R80.2
unnamed: L1.2, NT4.1, R45.2
unnamed: NT1.1, R38.2
unnamed: NT2.1, R39.2
unnamed: Q1.1 (B), R3.1
unnamed: Q1.3 (C), R1.2, SW1.1 (A)
unnamed: Q2.3 (D), R6.1
unnamed: Q3.3 (D), R7.1
unnamed: Q5.2 (G), R14.1
unnamed: Q6.2 (G), R16.1
unnamed: C17.1, C18.1, C22.2, R17.2, TP6.1, U1.47 (BAT)
unnamed: R24.1, U1.36 (REGIN), U1.37 (BREG)
unnamed: C22.1, U1.46 (CP1)
unnamed: R25.1, U1.34 (REG2), U1.35 (REG1)
unnamed: R42.2, U2.3 (EN)
unnamed: C46.1, U2.1 (VCAP)

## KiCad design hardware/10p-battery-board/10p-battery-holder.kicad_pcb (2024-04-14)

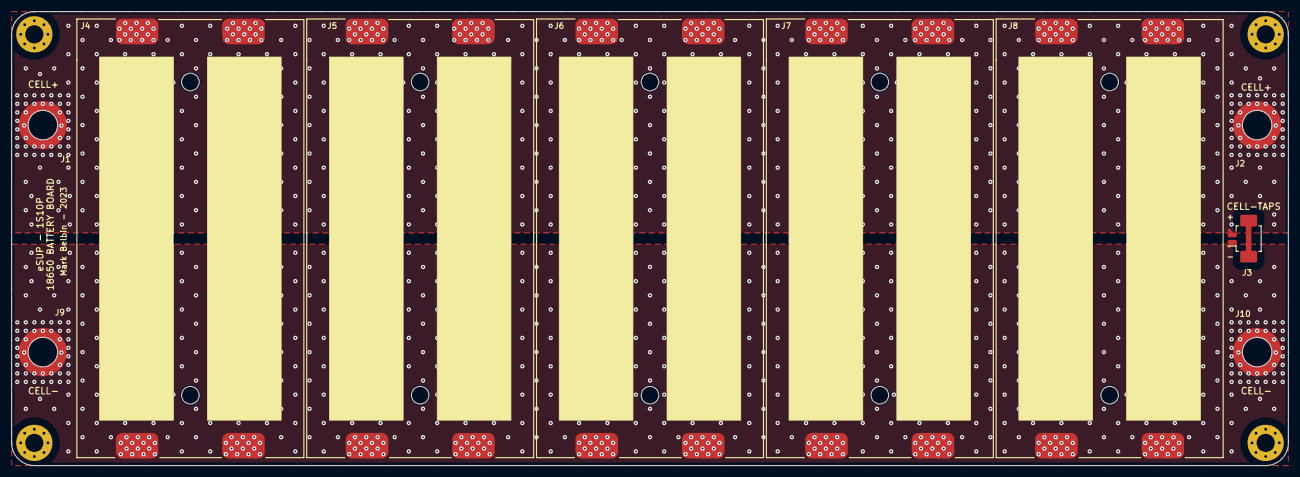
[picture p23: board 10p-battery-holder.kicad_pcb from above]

Board: 2 copper layers, 225.0 x 80.0 mm, 14 parts (0 on the bottom side), 2 nets.

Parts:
H1, H2, H3, H4: MountingHole_Pad; MountingHole_3.2mm_M3_Pad_Via
J1, J2, J9, J10: Screw_Terminal_01x01; Wurth_746600430R
J3: Conn_01x02; Molex_PicoBlade_53261-0271_1x02-1MP_P1.25mm_Horizontal
J4, J5, J6, J7, J8: dual_18650_battery_holder

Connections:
/CELL+: J1.1, J2.1, J3.2, J4.1 (CELL1+), J4.2 (CELL2+), J5.1 (CELL1+), J5.2 (CELL2+), J6.1 (CELL1+), J6.2 (CELL2+), J7.1 (CELL1+), J7.2 (CELL2+), J8.1 (CELL1+), J8.2 (CELL2+)
/CELL-: J3.1, J4.3 (CELL1-), J4.4 (CELL2-), J5.3 (CELL1-), J5.4 (CELL2-), J6.3 (CELL1-), J6.4 (CELL2-), J7.3 (CELL1-), J7.4 (CELL2-), J8.3 (CELL1-), J8.4 (CELL2-), J9.1, J10.1

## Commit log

2023-10-09 added existing CAD SolidWorks files plus docs
    [BATTERY, 18650.SLDPRT, BESC500-R1.SLDPRT, ENCLOSURE, BASE.SLDPRT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]
2023-10-09 created bms PCBA project
    [bms.kicad_pcb, bms.kicad_sch, bms.sch]
2023-10-09 added template sch pages
    [bms.sch, charger.sch, input.sch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]
2023-10-10 Created battery manager and charger IC symbols.
    [bms.sch, charger.sch, input.sch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]
2023-10-11 More progress on battery management circuit
    [bms.sch, monitor.sch]
2023-10-16 Battery monitor / balancer schematic complete. Charger is next. Thinking of adding MCU directly to this board if layout space allows, probably doesn't deserve its own board (or just deserves a dev bo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
    [CUI_DEVICES_DS04-254-2-01BK-SMT-TR.step, TDSON-8-1.step, bms.sch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]
2023-10-16 Selected connectors for cell taps, in/out power, charger, and enable switch.
    [bms.sch]
2023-10-18 Created footprints for microfit and wurth screw terminals
    [436500214.stp, 746600430.stp, 7466114.stp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]
2023-10-21 Resaved projected with KiCAD v7
    [battery_gauge.kicad_sch, bms.kicad_sch, bms.sch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]
2023-10-22 Added charger and pack fuses directly to board
    [0679L9150-01.step, FUSE_0ACH-9800-TE_BEL.step, bms.kicad_sch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]
2023-10-23 More charger sch progress
    [bms.kicad_sch, charger.kicad_sch, mcu.kicad_sch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]
2023-10-23 Added another thermistor for charger temp sensings. 9 total for the whole pack now
    [bms.kicad_sch, charger.kicad_sch]
2023-10-24 Made more progress on charger sch. Need to complete power stage next. Also added diode OR for MCU power conv input. Still deciding on converter selection
    [532611071.step, bms.kicad_sch, charger.kicad_sch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]
2023-10-25 Selected charger FETs, replaced other charger FETs to match. FETs rated for 40V since this is a 6S board (25.2V MAX). Also downsized the discharge FETs to be smaller and cheaper by selecting 40V FETs.
    [PG-TSDSON-8-12_INF.step, charger.kicad_sch, monitor.kicad_sch]
2023-10-26 Charger schematic complete! Only MCU left.
    [HCM1307-R.STEP, bms.kicad_sch, charger.kicad_sch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]
2023-10-27 Choose MCU as ESP32-C3-MINI. Small form factor with just enough I/O.
    [bms.kicad_sch, charger.kicad_sch, mcu.kicad_sch]
2023-10-28 Added BJT to enable BMS/MCU when charger input voltage present
    [DCK0005A.stp, bms.kicad_sch, mcu.kicad_sch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]
2023-10-29 Selected power conversion scheme and converters.
    [bms.kicad_sch, mcu.kicad_sch]
2023-10-29 MCU power conversion section complete
    [IND_1050P-WE-PD_WRE.step, bms.kicad_sch, charger.kicad_sch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]
2023-10-29 Sch mostly complete! Just have the USB C connector left to sort out.
    [B3U-1000P.step, bms.kicad_sch, charger.kicad_sch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]
2023-10-29 Updated USB C connector, fixed all sch ERC errors, imported footprints into pcb file, fixed any pcb import errors.
    [bms.kicad_pcb, bms.kicad_sch, mcu.kicad_sch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]
2023-10-29 Sch cleanup, added extra netties
    [bms.kicad_pcb, bms.kicad_sch, charger.kicad_sch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]
2023-10-31 Continued layout, defined board area based on mech assembly
    [ENCLOSURE, PLATE, ASM.SLDASM, ENCLOSURE, PLATE.SLDPRT, ETQP5M3R3YFK.step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]
2023-11-01 Updated test points to 0.5mm to save space, continued layout
    [bms.kicad_pcb, bms.kicad_sch, charger.kicad_sch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]
2023-11-01 Simplified chassis connection, only at one mounting hole and left other holes NC (no chassis plane on PCB
    [bms.kicad_pcb, bms.kicad_sch]
2023-11-01 Some routing for thermistors and cell taps to see if it works
    [bms.kicad_pcb]
2023-11-01 refined routing near cell taps
    [bms.kicad_pcb]
2023-11-03 More layout, changed precharge / predischarged PMOS selection to SOT-23 size to save space. Charger layout will be difficult, may need to change charger input terminal location...
    [bms.kicad_pcb, charger.kicad_sch, monitor.kicad_sch]
2023-11-04 Changed large input fuse, slightly smaller and cheaper, 60A rated. Layout more defined, charger layout much better now
    [SF-3812F-T.stp, bms.kicad_pcb, bms.kicad_sch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]
2023-11-05 Added Micro SD card circuit.
    [1040310811.stp, bms.kicad_pcb, bms.kicad_sch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]
2023-11-05 Layout complete! MicroSD card fits just fine
    [bms.kicad_pcb]
2023-11-05 Modified layout to fit inside enclosure and around penetrators. Routing time!
    [bms.kicad_pcb]
2023-11-06 Power plane and thermal vias for charger and FETs section
    [bms.kicad_pcb]
2023-11-06 Few cross-board connections made, a bit tricky to work around power planes
    [bms.kicad_pcb]
2023-11-07 Added extra features to try and prevent SD card data corruption. Added override enable so that the MCU can keep itself on until the SD card is finished writing, also added 5V / wake detect circuit so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
    [bms.kicad_pcb, bms.kicad_sch, mcu.kicad_sch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]
2023-11-07 Added bulk cap for 5V and 3V3 rails, made sure they fit in current layout
    [bms.kicad_pcb, bms.kicad_sch, mcu.kicad_sch]
2023-11-08 Swapped out SD card holder to a push-push version, should be nicer. Also a lot of routing and power plane work
    [503398-1892.step, bms.kicad_pcb, mcu.kicad_sch]
2023-11-08 More routing, just 3V3 and 5V power planes to go, then ground via stiching
    [bms.kicad_pcb]
2023-11-09 Working through DRC errors. All nets connected, need to double check JLCPCB design rules
    [bms.kicad_pcb]
2023-11-10 Added board cutout for antenna, recommended by ESP32 docs
    [bms.kicad_pcb]
2023-11-10 All DRC errors cleared, updated design rules based off JLCs specs
    [bms.kicad_pcb]
2023-11-10 Board essentially finished! All silkscreen cleaned up, all DRC errors cleared.
    [bms.kicad_pcb]
2023-11-10 Added board dimensions to dimension layer
    [bms.kicad_pcb]
2023-11-11 Added keystone clip test points for ground, should be nice
    [5019.step, bms.kicad_pcb, monitor.kicad_sch]
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2023-11-12 Review of BMS board looks good, finished!
    [bms.kicad_pcb, bms.kicad_sch, charger.kicad_sch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]
2023-11-12 Created battery holder PCBA project, sch finished, basic board layout finished
    [10p-battery-holder.kicad_pcb, 10p-battery-holder.kicad_sch, 746600430.stp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]
2023-11-12 Finished battery holder board!
    [10p-battery-holder.kicad_pcb, 10p-battery-holder.kicad_sch, bms.kicad_sch]
2023-11-13 Updated mech assembly with battery board, looks good. Ordering V1 PCBs!
    [10p-battery-holder.kicad_pcb, 10p-battery-holder.kicad_sch, 746600430.stp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]
2023-11-13 Exported gerbers for both boards
    [10p-battery-holder-B_Cu.gbl, 10p-battery-holder-B_Mask.gbs, 10p-battery-holder-B_Paste.gbp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]
2023-11-16 Updated MFG PNs, BOM ordered.
    [bms.kicad_sch, charger.kicad_sch, mcu.kicad_sch]
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
